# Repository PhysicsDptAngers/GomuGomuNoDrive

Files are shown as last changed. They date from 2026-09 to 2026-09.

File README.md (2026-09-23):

# Rubber Zener (GomuGomuNoDrive): Analog Circuit & Anti-Aliased Virtual Analog Model

This repository provides open-source hardware designs, physical bench measurement datasets, numerical simulation routines, and real-time DSP emulations for the **Rubber Zener** clipping topology.

The Rubber Zener is a parameterized audio clipping circuit based on the bipolar junction transistor (BJT) $V_{be}$ multiplier, augmented with local passive and reactive networks. It allows decoupled analog tuning of positive and negative conduction thresholds, soft-knee transition slopes, deep-saturation current ceilings, frequency-dependent clipping profiles, and envelope-dependent DC baseline sag.

> **Academic Context:**  
> This repository contains the reference implementation, experimental datasets, and validation routines accompanying the research paper:  
> *The Rubber Zener Clipping Topology: Circuit Analysis, Dynamic Characterization, and Anti-Aliased Virtual Analog Modeling* (currently under peer review).

---

## コムコム の Drive  (Gomu Gomu No Drive) ?

The $V_{be}$ multiplier circuit is sometimes called "Rubber Zener" because, like rubber, its threshold is malleable. In pop culture, the most well-known "rubber man" is *Luffy* (ルフィ) from *One Piece* (ワンピース). His iconic attack names start with "ゴムゴム" (Gomu Gomu) since ゴム (gomu) in Japanese means rubber. Hence the name of this distortion pedal: コムコム の Drive (Gomu Gomu No Drive).

---

## Repository Structure

```text
GomuGomuNoDrive/
├── Data/
│   ├── AC/                                # AC bench measurements, steady-state datasets, and fitting scripts
│   └── DC characteristics/                # Static I-V measurement datasets
├── Hardware/
│   ├── GomuGomuNoDrive_hard/              # Shunt dipole hard-clipping implementation (KiCad, 3D models, Gerbers)
│   └── GomuGomuNoDrive_Soft/              # Feedback loop soft-clipping implementation (KiCad, BOM, production files)
├── NumericalSimulation/                   # SPICE benchmarks, 4D ODE solvers, harmonic balance, and validation routines
└── Software/
    ├── Faust/                             # Faust core DSP architecture and C++ wrappers
    ├── JesuSonic/                         # Real-time JSFX implementation for Cockos REAPER
    └── Juce Plugin/                       # Full C++ audio plugin project (VST3, CLAP, LV2, Standalone)
```

#### Pre-compiled Binaries

Pre-compiled binaries for 64-bit Windows and Linux systems (VST3 and Standalone) are provided under the [Releases](../../releases) section.

---

## License

This project adopts a multi-licensing scheme adapted to its different components:

- **Software** (JUCE audio plugin, DSP solvers, simulation scripts): Licensed under the [GNU General Public License v3.0](LICENSE-GPL.txt) (GPL-3.0-or-later). Bundled cabinet impulse responses are licensed under GPL-2.0-or-later (Copyright © 2013 David Fau Casquel / Guitarix project).
- **Hardware** (KiCad schematics, PCB layouts, manufacturing files): Licensed under the [CERN Open Hardware Licence Version 2 – Strongly Reciprocal](LICENSE-CERN.txt) (CERN-OHL-S-2.0).
- **Documentation & Data** (Manuscript, figures, measurement datasets): Licensed under the [Creative Commons Attribution 4.0 International License](https://creativecommons.org/licenses/by/4.0/) (CC-BY-4.0).

---

## Citation

If you use this circuit topology, DSP implementation, or dataset in academic work or derivative projects, please cite:

TBA !

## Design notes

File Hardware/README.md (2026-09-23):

# Hardware

Contains complete CAD files, schematics, PCB layouts, and fabrication packages:

* **`GomuGomuNoDrive_hard`**: The primary shunt-to-ground clipping dipole topology characterized in the paper.
* **`GomuGomuNoDrive_Soft`**: Alternative operational amplifier feedback implementation (compatible with classic LM308 / dual op-amp footprints).

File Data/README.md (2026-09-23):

# Experimental Data 

Physical bench measurements acquired via digital storage oscilloscopes and automated SCPI test benches:

* **`Data/AC`**: Calibrated time-domain AC voltage captures across various frequency and reactive network configurations, along with global parameter extraction scripts.
* **`Data/DC characteristics`**: Quasi-static $I-V$ sweeps documenting threshold voltage shifts ($\alpha$), soft-knee curvature ($R_k$), and plateau resistance ($R_p$).

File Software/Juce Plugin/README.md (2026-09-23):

# GomuGomuNoDrive — JUCE Audio Plugin

This directory contains the reference C++ implementation of the **GomuGomuNoDrive** (Rubber Zener) virtual analog audio plugin built with the [JUCE framework](https://juce.com/) (version 8.0.13).

The plugin features:
- A real-time, four-dimensional implicit Newton-Raphson solver modeling the physical Ebers-Moll BJT transport equations and Shockley diode characteristics.
- 2x polyphase half-band IIR multirate oversampling (>90 dB stopband rejection).
- Dual 12-band graphic equalizers (pre-distortion drive sculpting and post-distortion tone shaping).
- Dynamic CRT-style visualizers (static I/V transfer characteristic and real-time dual-trace time-domain waveform monitor).
- Integrated zero-latency cabinet impulse response (IR) convolution engine.
- Targets: **VST3**, **CLAP**, **LV2**, and **Standalone**.

---

## Important Files

- `CMakeLists.txt` — CMake build configuration and target definitions.
- `PluginProcessor.h` / `PluginProcessor.cpp` — Core DSP pipeline: APVTS parameter layout, implicit 4D Newton-Raphson solver (`RubberZener`), oversampler, and convolution engine.
- `PluginEditor.h` / `PluginEditor.cpp` — Graphical user interface, custom hardware LookAndFeel (Davies 1510 knobs, vintage levers), graphic EQ components, and CRT scopes.
- `Resources/IR/` — Bundled speaker cabinet impulse response collections (`BestPlugins_Amps` and `BestPlugins_Bands`).

---

## Building from CLI

> **Note:** Pre-compiled binaries for Linux and Windows (VST3, CLAP, Standalone) are available under the GitHub [Releases](../../releases) section if you do not wish to build from source.

### Linux (Debian / Ubuntu)

1. **Install system dependencies:**

   ```bash
   sudo apt update
   sudo apt install -y build-essential cmake ninja-build git \
       libasound2-dev libjack-jackd2-dev libgl1-mesa-dev libglu1-mesa-dev \
       libx11-dev libxinerama-dev libxext-dev libfreetype6-dev
   ```

2. **Clone the JUCE framework (tested with version 8.0.13):**

#### Option A: Tested version (8.0.13)
git clone --depth 1 --branch 8.0.13 https://github.com/juce-framework/JUCE.git JUCE

#### Option B: Latest version (master branch)
git clone --depth 1 https://github.com/juce-framework/JUCE.git JUCE

3. **Configure and compile with CMake and Ninja:**

   ```bash
   cmake -B build -G Ninja -DCMAKE_BUILD_TYPE=Release
   cmake --build build --config Release -j$(nproc)
   ```

   Compiled artifacts (VST3, CLAP, LV2, and Standalone binary) will be generated inside `build/GomuGomuNoDrive_artefacts/Release/`.

---

### Windows (CLI)

1. **Prerequisites:**
   - Visual Studio Build Tools (or Visual Studio Community) with the **C++ Desktop Development** workload installed.
```powershell
winget install --id Microsoft.VisualStudio.2022.BuildTools --override "--passive --wait --add Microsoft.VisualStudio.Workload.VCTools --includeRecommended"
```

   - [CMake](https://cmake.org/download/) (>= 3.22) and [Git](https://git-scm.com/) added to your system `PATH`.
   - Optional: [Ninja](https://github.com/ninja-build/ninja/releases) for faster parallel builds.

```powershell
# Git and CMake
winget install --id Git.Git -e --source winget
winget install --id Kitware.CMake -e --source winget --override "ADD_CMAKE_TO_PATH=System"

# Ninja (optionnal)
winget install --id Ninja-build.Ninja -e --source winget
```

2. **Clone the JUCE framework (version 8.0.13):**

   Open PowerShell or the Developer Command Prompt:

   ```powershell
   git clone --depth 1 --branch 8.0.13 https://github.com/juce-framework/JUCE.git JUCE
   ```

3. **Configure and compile:**

   *Using Ninja (from Developer Command Prompt):*
   ```powershell
   cmake -B build -G Ninja -DCMAKE_BUILD_TYPE=Release
   cmake --build build --config Release
   ```

   *Or using the default MSVC generator:*
   ```powershell
   cmake -B build -G "Visual Studio 17 2022" -A x64
   cmake --build build --config Release --parallel
   ```

   Binaries will be available in `build/GomuGomuNoDrive_artefacts/Release/`.

---

## Impulse Responses (IR) & Licensing

- **Plugin Source Code:** Released under the [GNU General Public License v3.0](https://www.gnu.org/licenses/gpl-3.0.html) (GPL-3.0-or-later).
- **Cabinet Impulse Responses (`Resources/IR/`):** Sourced from the open-source **Guitarix** project, collected and created by David Fau Casquel (BestPlugins). These IR files are licensed under the [GNU General Public License v2.0](https://www.gnu.org/licenses/old-licenses/gpl-2.0.html) (GPL-2.0-or-later). See `Resources/IR/BestPlugins_Amps/LICENSE` and `Resources/IR/BestPlugins_Bands/LICENSE` for full notices.

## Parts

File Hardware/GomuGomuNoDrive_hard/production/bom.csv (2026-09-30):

Designator | Footprint | Quantity | Value | LCSC Part #
C1 | 0805 | 1 | 22n - film
C10, C14, C15 | 0805 | 3 | 100n
C11, C17, C5, C7 | 0805 | 4 | 22n
C12, C13, C16 | 0805 | 3 | 1u
C18 | 0805 | 1 | 10u
C2, C3 | 0805 | 2 | 4n7
C6 | 0805 | 1 | 220n
C8, C9 | 0805 | 2 | 10n
D1, D2, D3 | D_SOD-123 | 3 | C8598
D4 | LED_D5.0mm_Clear | 1 | LED
J1 | BarrelJack_Horizontal | 1 | 9V
J2, J3 | Jack_6.35mm_Neutrik_NMJ6HCD2_Horizontal | 2 | AudioJack3
J5 | JST_EH_B6B-EH-A_1x06_P2.50mm_Vertical | 1 | Conn_01x06_Socket
Q1, Q2 | SOT-23 | 2 | BC850
R10 | 0805 | 1 | 1M
R11, R13, R16 | 0805 | 3 | 4k7
R12, R14, R15 | 0805 | 3 | 100
R17 | 0805 | 1 | 10k
R9 | 0805 | 1 | 6K8
RV11 | Potentiometer_Alpha_RD901F-40-00D_Single_Vertical | 1 | 100K_Log
RV12, RV5, RV6, RV8 | Potentiometer_Alpha_RD901F-40-00D_Single_Vertical | 4 | 5K
RV21 | Potentiometer_Alpha_RD901F-40-00D_Single_Vertical | 1 | 100K Log
RV3, RV4 | Potentiometer_Alpha_RD901F-40-00D_Single_Vertical | 2 | 50K
SW10, SW7, SW8 | SS12D00 | 3 | SW_DPDT_x2
SW11 | SS12D00 | 1 | SW_SPDT
SW3, SW4 | SW_MINI-SPDT-SW | 2 | SW_DPDT_x2
SW5, SW6 | SW_MINI-SPDT-SW | 2 | SW_SPDT_MSM
TP20 | PinHeader_1x01_P2.54mm_Vertical | 1 | -9V
TP21 | PinHeader_1x01_P2.54mm_Vertical | 1 | In
TP22 | PinHeader_1x01_P2.54mm_Vertical | 1 | In_DC
TP23 | PinHeader_1x01_P2.54mm_Vertical | 1 | pre_diode
TP24 | PinHeader_1x01_P2.54mm_Vertical | 1 | post_diode
TP25 | PinHeader_1x01_P2.54mm_Vertical | 1 | GND
TP26 | PinHeader_1x01_P2.54mm_Vertical | 1 | out
TP27 | PinHeader_1x01_P2.54mm_Vertical | 1 | 9V
U2 | SOIC-8_3.9x4.9mm_P1.27mm | 1 | TC7662Bx0A
U5 | SOIC-14_3.9x8.7mm_P1.27mm | 1 | OPA1679

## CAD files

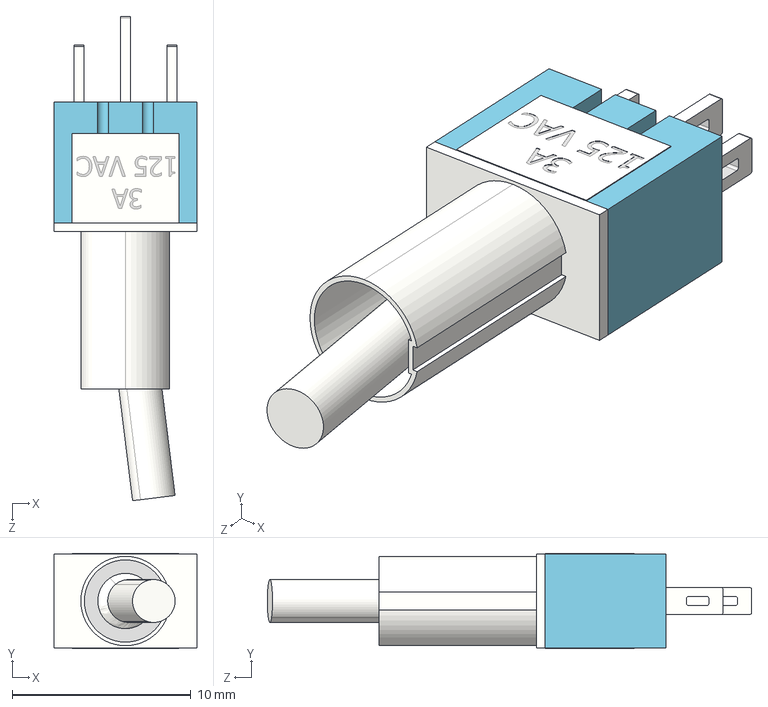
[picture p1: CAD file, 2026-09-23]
Hardware/GomuGomuNoDrive_hard/User Library-Toggle Switch Full.STEP
8.00 x 5.34 x 27.1 mm
Toggle Switch 3a 125V AC Lever
Toggle Switch 3a 125V AC

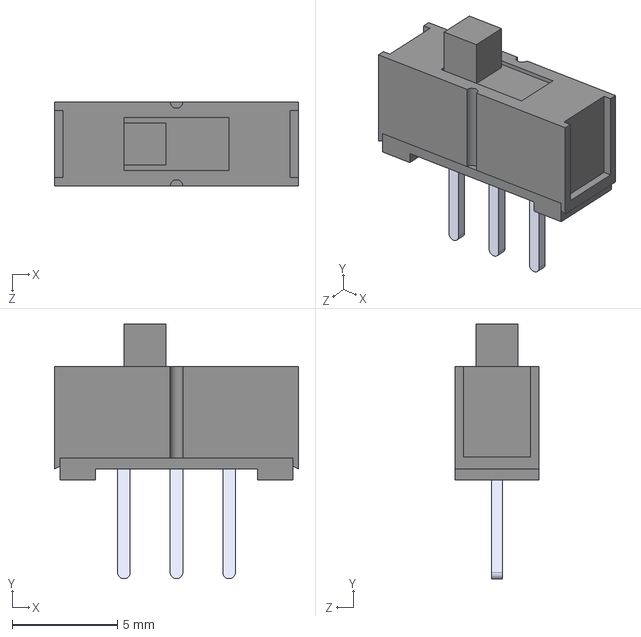
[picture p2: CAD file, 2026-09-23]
Hardware/GomuGomuNoDrive_hard/MINI-SPDT-SW.step
11.6 x 12.1 x 4.00 mm

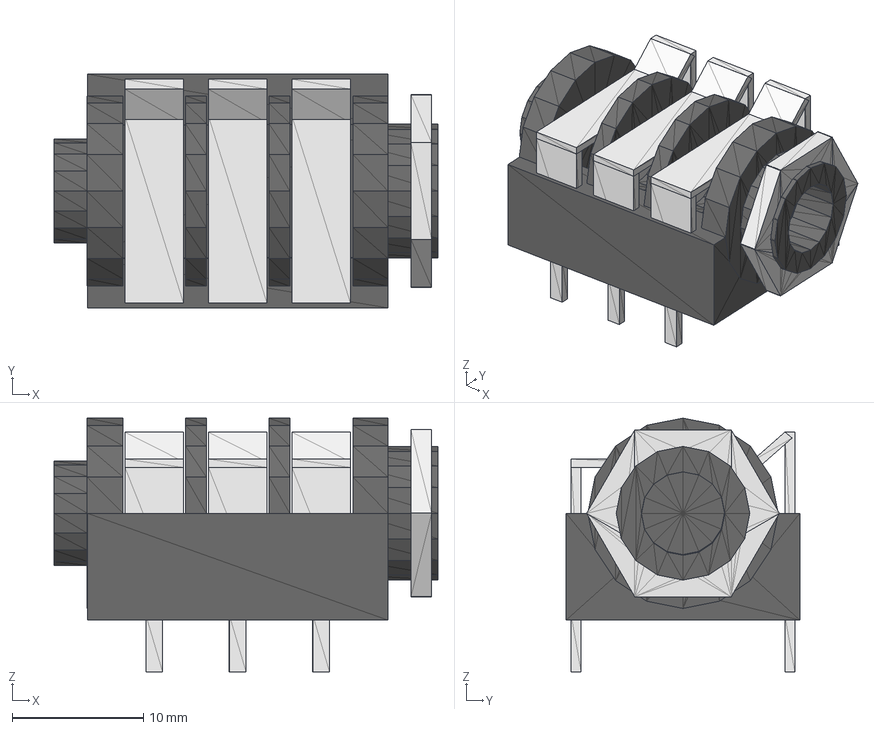
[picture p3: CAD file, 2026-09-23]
Hardware/GomuGomuNoDrive_Soft/NEUTRIKJKST.stp
29.2 x 17.8 x 19.3 mm
NEUTRIKJKST_2
NEUTRIKJKST_3
NEUTRIKJKST_4
NEUTRIKJKST_5
NEUTRIKJKST_6
NEUTRIKJKST_7
NEUTRIKJKST_8
NEUTRIKJKST_9
NEUTRIKJKST_10
NEUTRIKJKST_11
NEUTRIKJKST_12
NEUTRIKJKST_13
NEUTRIKJKST_14
NEUTRIKJKST_15
NEUTRIKJKST_16
NEUTRIKJKST_17
NEUTRIKJKST_18
NEUTRIKJKST_19
NEUTRIKJKST_20
NEUTRIKJKST_21
NEUTRIKJKST_22
NEUTRIKJKST_23
NEUTRIKJKST_24
NEUTRIKJKST_25
NEUTRIKJKST_26
NEUTRIKJKST_27
NEUTRIKJKST_28
NEUTRIKJKST_29
NEUTRIKJKST_30
NEUTRIKJKST_31
NEUTRIKJKST_32

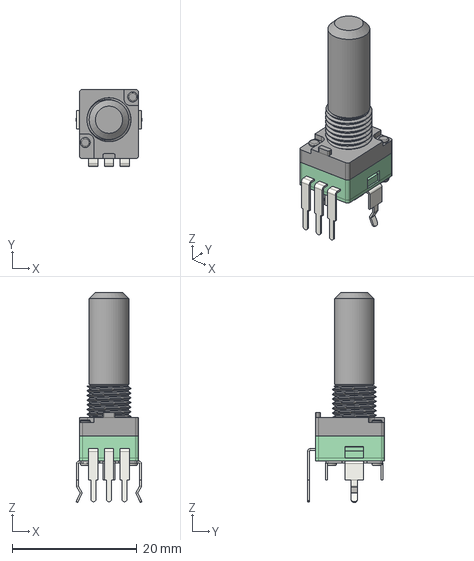
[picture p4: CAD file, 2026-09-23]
Hardware/GomuGomuNoDrive_Soft/ALPHA-RD901F-40.step
10.6 x 12.3 x 33.6 mm

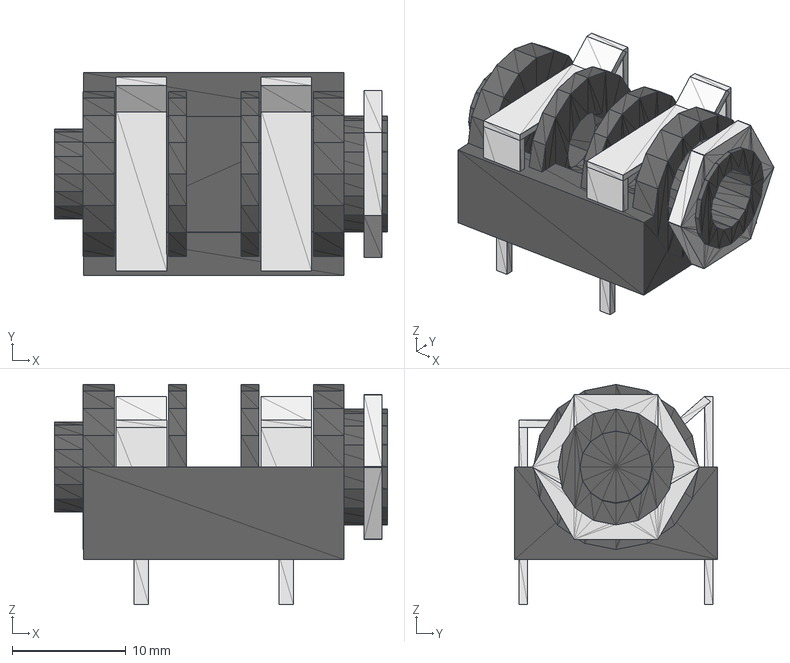
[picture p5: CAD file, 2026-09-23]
Hardware/GomuGomuNoDrive_Soft/NEUTRIKJK.stp
29.2 x 17.8 x 19.3 mm
NEUTRIKJK_2
NEUTRIKJK_3
NEUTRIKJK_4
NEUTRIKJK_5
NEUTRIKJK_6
NEUTRIKJK_7
NEUTRIKJK_8
NEUTRIKJK_9
NEUTRIKJK_10
NEUTRIKJK_11
NEUTRIKJK_12
NEUTRIKJK_13
NEUTRIKJK_14
NEUTRIKJK_15
NEUTRIKJK_16
NEUTRIKJK_17
NEUTRIKJK_18
NEUTRIKJK_19
NEUTRIKJK_20
NEUTRIKJK_21
NEUTRIKJK_22
NEUTRIKJK_23
NEUTRIKJK_24
NEUTRIKJK_25
NEUTRIKJK_26

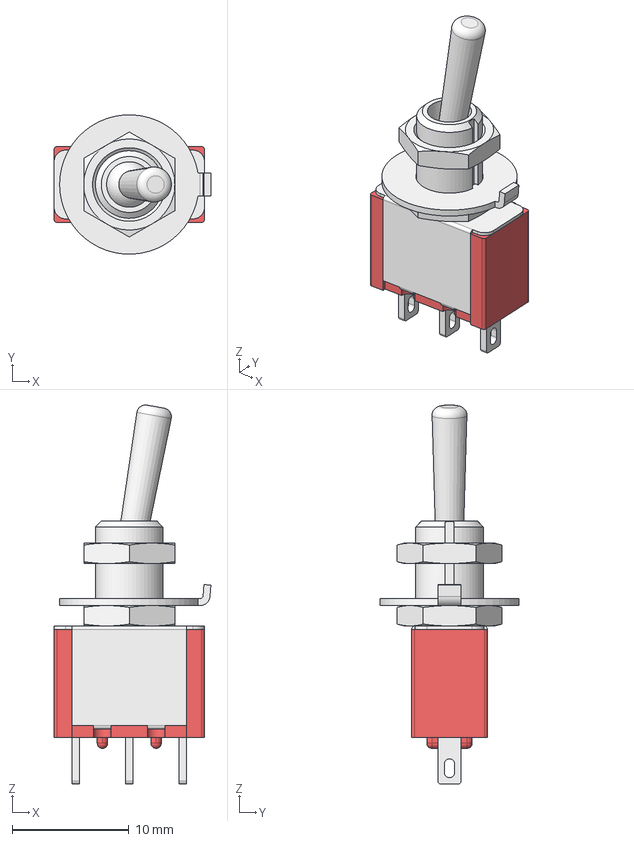
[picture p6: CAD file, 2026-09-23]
Hardware/GomuGomuNoDrive_hard/6mm SPDT Mini Toggle Switch.step
13.4 x 11.9 x 32.5 mm

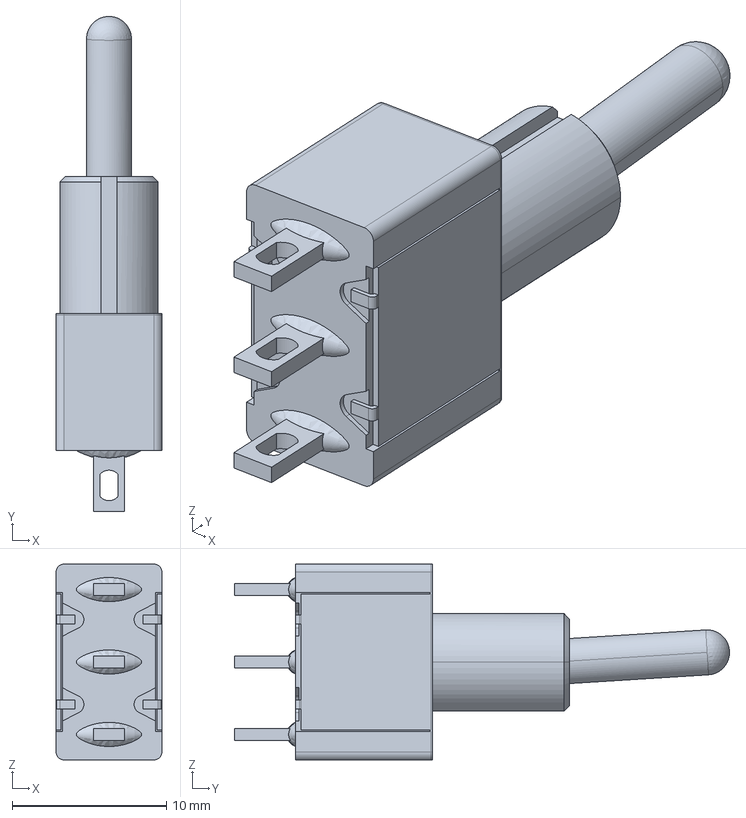
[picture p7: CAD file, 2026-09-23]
Hardware/GomuGomuNoDrive_hard/toggle_switch_1ms1t1b1m1qes.stp
6.86 x 32.1 x 12.7 mm

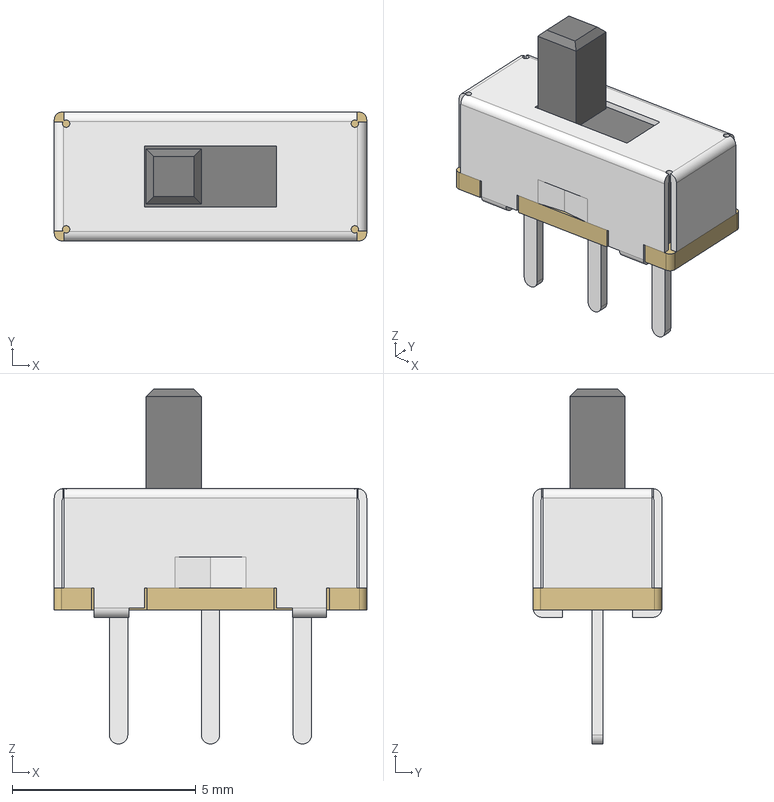
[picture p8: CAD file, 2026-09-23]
Hardware/GomuGomuNoDrive_hard/SPDT slide switch SS12D00.step
8.50 x 3.50 x 9.66 mm

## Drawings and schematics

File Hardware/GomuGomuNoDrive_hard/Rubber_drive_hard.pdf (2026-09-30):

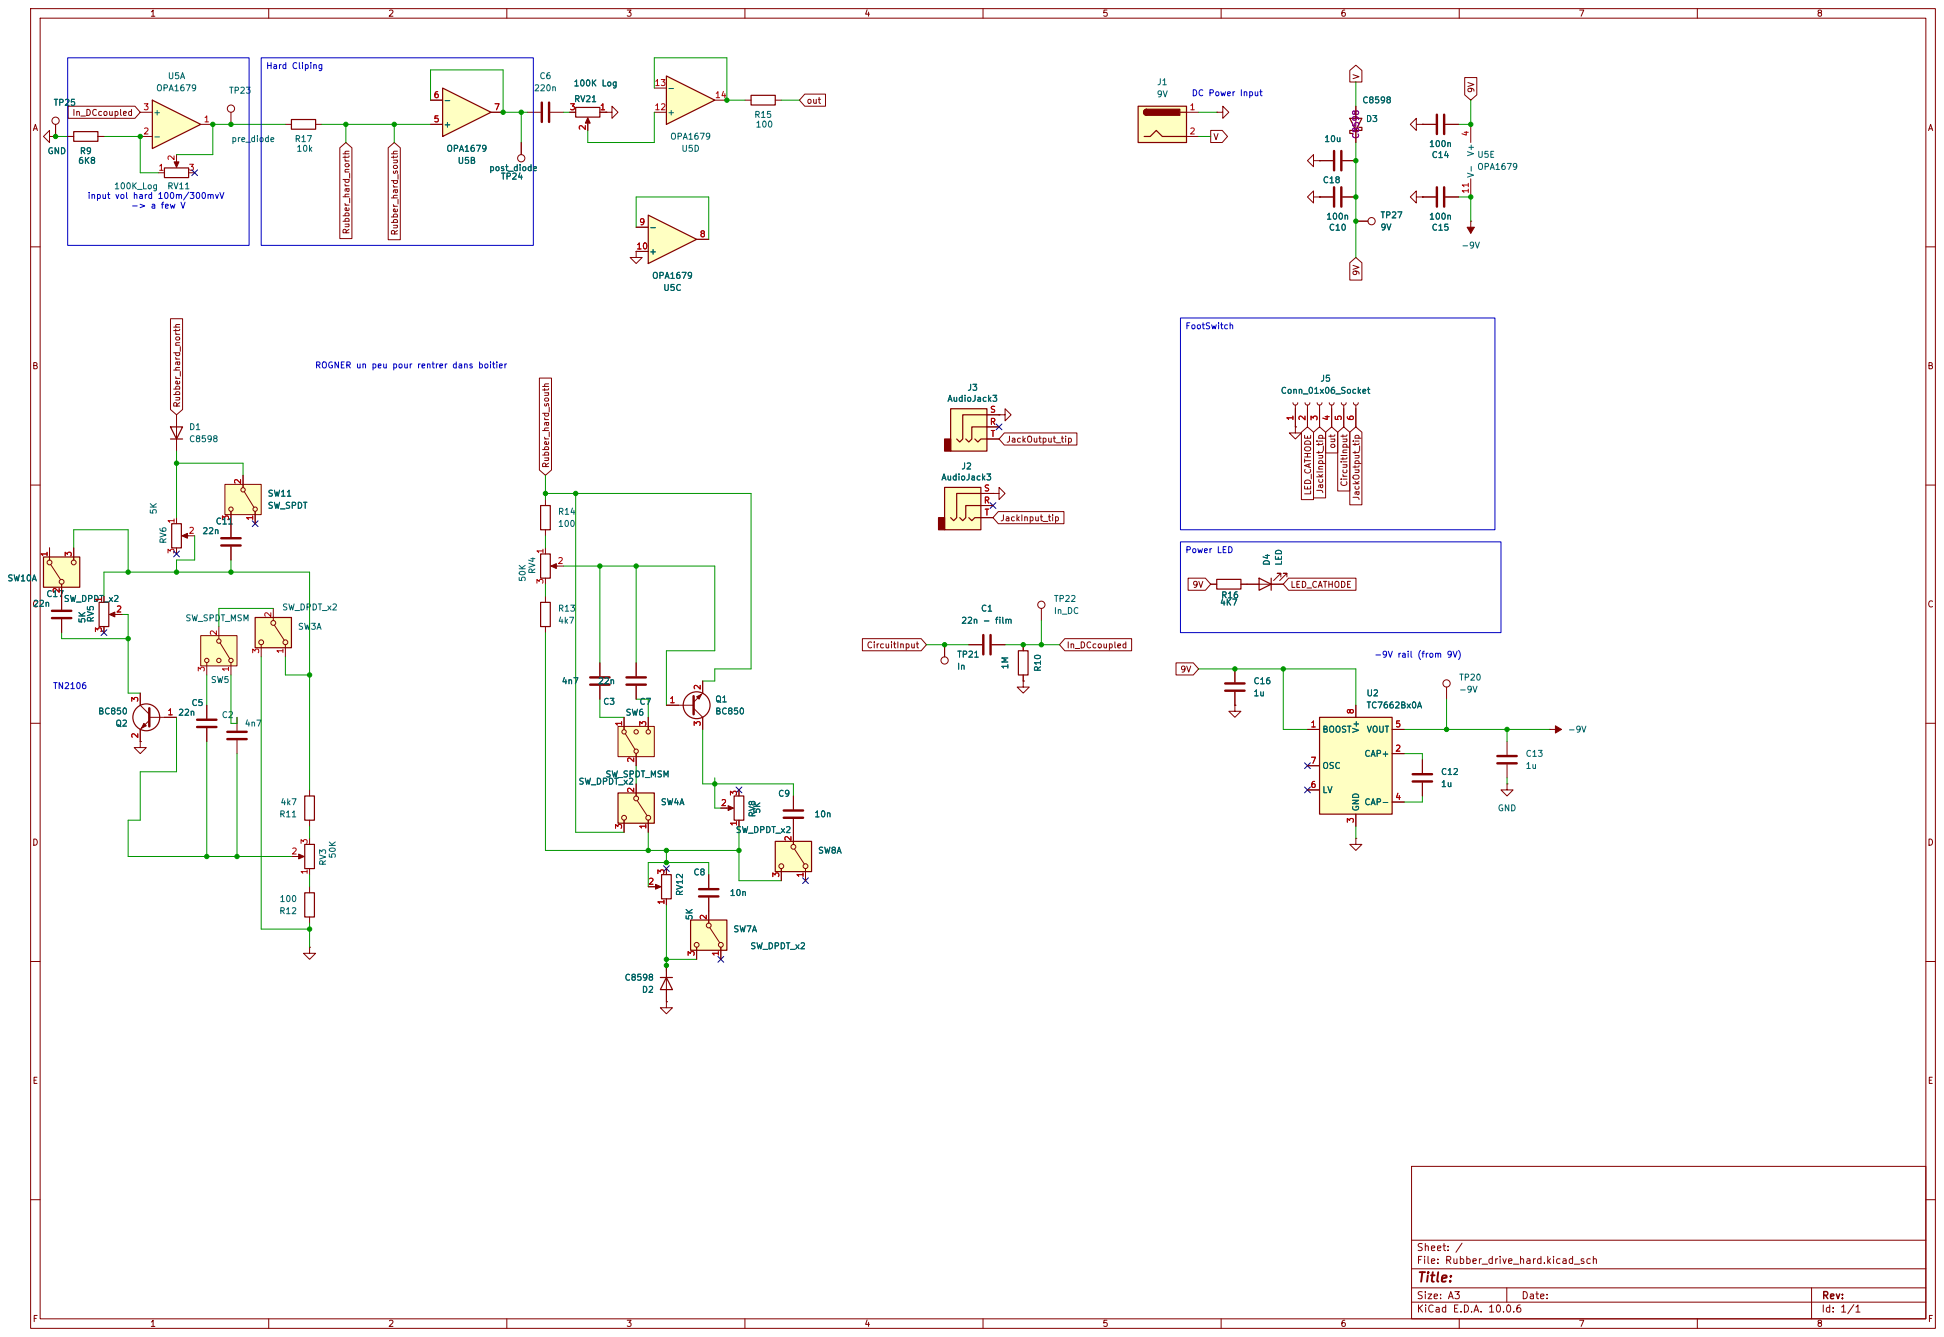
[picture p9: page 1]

Size: A3 | Rev: | F Date:
KiCad E.D.A. 10.0.6 | Id: 1/1

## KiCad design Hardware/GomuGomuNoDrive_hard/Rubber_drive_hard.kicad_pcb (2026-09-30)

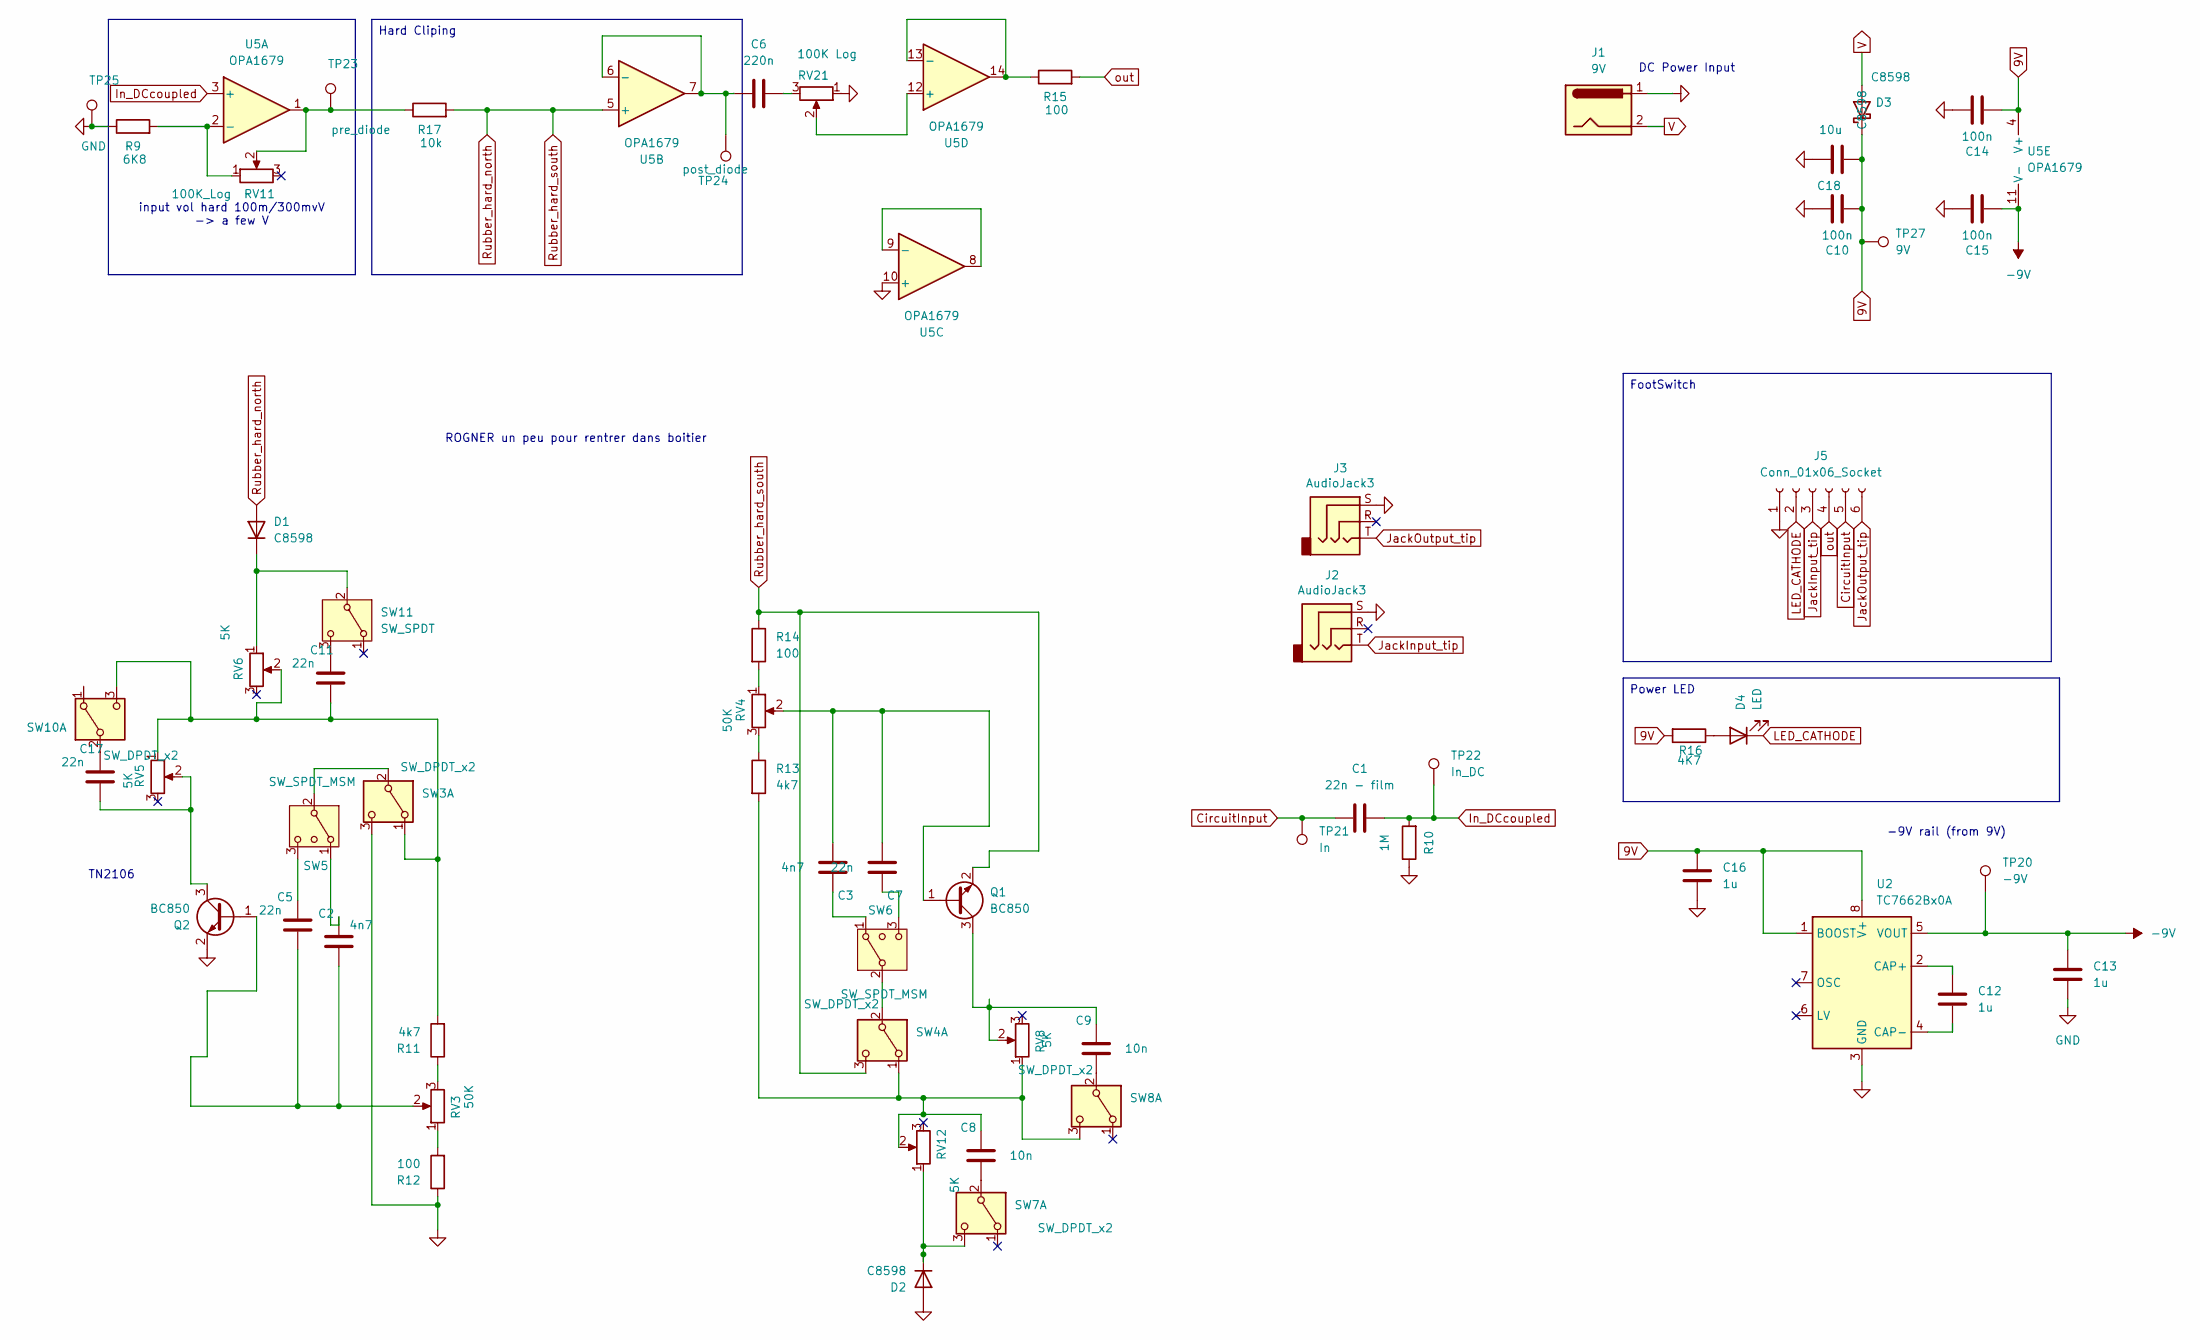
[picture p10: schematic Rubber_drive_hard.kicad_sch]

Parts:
C1: 22n - film; C_0805_2012Metric_Pad1.18x1.45mm_HandSolder
C2, C3: 4n7; C_0805_2012Metric_Pad1.18x1.45mm_HandSolder
C5, C7, C11, C17: 22n; C_0805_2012Metric_Pad1.18x1.45mm_HandSolder
C6: 220n; C_0805_2012Metric_Pad1.18x1.45mm_HandSolder
C8, C9: 10n; C_0805_2012Metric_Pad1.18x1.45mm_HandSolder
C10, C14, C15: 100n; C_0805_2012Metric_Pad1.18x1.45mm_HandSolder
C12, C13, C16: 1u; C_0805_2012Metric_Pad1.18x1.45mm_HandSolder
C18: 10u; C_0805_2012Metric_Pad1.18x1.45mm_HandSolder
D1, D2, D3: C8598; D_SOD-123
D4: LED; LED_D5.0mm_Clear
J1: 9V; BarrelJack_Horizontal
J2, J3: AudioJack3; Jack_6.35mm_Neutrik_NMJ6HCD2_Horizontal
J5: Conn_01x06_Socket; JST_EH_B6B-EH-A_1x06_P2.50mm_Vertical
Q1, Q2: BC850; SOT-23
R9: 6K8; R_0805_2012Metric_Pad1.20x1.40mm_HandSolder
R10: 1M; R_0805_2012Metric_Pad1.20x1.40mm_HandSolder
R11, R13: 4k7; R_0805_2012Metric_Pad1.20x1.40mm_HandSolder
R12, R14, R15: 100; R_0805_2012Metric_Pad1.20x1.40mm_HandSolder
R16: 4K7; R_0805_2012Metric_Pad1.20x1.40mm_HandSolder
R17: 10k; R_0805_2012Metric_Pad1.20x1.40mm_HandSolder
RV3, RV4: 50K; Potentiometer_Alpha_RD901F-40-00D_Single_Vertical
RV5, RV6, RV8, RV12: 5K; Potentiometer_Alpha_RD901F-40-00D_Single_Vertical
RV11: 100K_Log; Potentiometer_Alpha_RD901F-40-00D_Single_Vertical
RV21: 100K Log; Potentiometer_Alpha_RD901F-40-00D_Single_Vertical
SW3, SW4: SW_DPDT_x2; SW_MINI-SPDT-SW
SW5, SW6: SW_SPDT_MSM; SW_MINI-SPDT-SW
SW7, SW8, SW10: SW_DPDT_x2; SS12D00
SW11: SW_SPDT; SS12D00
TP20: -9V; PinHeader_1x01_P2.54mm_Vertical
TP21: In; PinHeader_1x01_P2.54mm_Vertical
TP22: In_DC; PinHeader_1x01_P2.54mm_Vertical
TP23: pre_diode; PinHeader_1x01_P2.54mm_Vertical
TP24: post_diode; PinHeader_1x01_P2.54mm_Vertical
TP25: GND; PinHeader_1x01_P2.54mm_Vertical
TP27: 9V; PinHeader_1x01_P2.54mm_Vertical
U2: TC7662Bx0A; SOIC-8_3.9x4.9mm_P1.27mm
U5: OPA1679; SOIC-14_3.9x8.7mm_P1.27mm

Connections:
9V: C10.2, C14.2, C16.2, C18.2, D3.1 (K), R16.2, TP27.1 (1_1), U2.1 (BOOST), U2.8 (V+), U5.4 (V+)
-9V: C13.2, C15.2, TP20.1 (1_1), U2.5 (VOUT), U5.11 (V-)
CircuitInput: C1.1, J5.5, TP21.1 (1_1)
GND: C10.1, C13.1, C14.1, C15.1, C16.1, C18.1, D2.2 (A), J1.1, J2.S, J3.S, J5.1, Q2.2 (E), R9.1, R10.1, R12.1, RV21.1, SW3.3 (C), TP25.1 (1_1), U2.3 (GND), U5.10 (+)
In_DCcoupled: C1.2, R10.2, TP22.1 (1_1), U5.3 (+)
JackInput_tip: J2.T, J5.3
JackOutput_tip: J3.T, J5.6
LED_CATHODE: D4.1 (K), J5.2
unnamed: C2.1, SW5.1
unnamed: C3.1, SW6.1
unnamed: C6.2, RV21.3
unnamed: D1.1 (K), RV6.1, SW11.2 (B)
unnamed: D2.1 (K), RV12.1, SW7.3 (C)
unnamed: D4.2 (A), R16.1
unnamed: C3.2, C7.2, Q1.1 (B), RV4.2
unnamed: C9.1, Q1.3 (C), RV8.2
unnamed: C2.2, C5.2, Q2.1 (B), RV3.2
unnamed: C17.2, Q2.3 (C), RV5.2
unnamed: R11.1, RV3.3
unnamed: R12.2, RV3.1
unnamed: R13.1, RV4.3
unnamed: R14.2, RV4.1
unnamed: R17.1, RV11.2, TP23.1 (1_1), U5.1
unnamed: SW3.2 (B), SW5.2 (3)
unnamed: C8.1, R13.2, RV8.1, RV12.2, SW4.1 (A), SW8.3 (C)
unnamed: SW4.2 (B), SW6.2 (3)
unnamed: C5.1, SW5.3 (4)
unnamed: C7.1, SW6.3 (4)
unnamed: C8.2, SW7.2 (B)
unnamed: C9.2, SW8.2 (B)
unnamed: C17.1, SW10.2 (B)
unnamed: C11.2, R11.2, RV5.1, RV6.2, SW3.1 (A), SW10.3 (C)
unnamed: C11.1, SW11.3 (C)
unnamed: C12.2, U2.2 (CAP+)
unnamed: C12.1, U2.4 (CAP-)
unnamed: R9.2, RV11.1, U5.2 (-)
unnamed: C6.1, TP24.1 (1_1), U5.6 (-), U5.7
unnamed: U5.8, U5.9 (-)
unnamed: RV21.2, U5.12 (+)
unnamed: R15.1, U5.13 (-), U5.14
Rubber_hard_north: D1.2 (A), Q1.2 (E), R14.1, R17.2, SW4.3 (C), U5.5 (+)
V: D3.2 (A), J1.2
out: J5.4, R15.2; also elsewhere on the board

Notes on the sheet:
input vol hard 100m/300mvV -> a few V
TN2106
-9V rail (from 9V)
ROGNER un peu pour rentrer dans boitier
DC Power Input
FootSwitch
Hard Cliping
Power LED

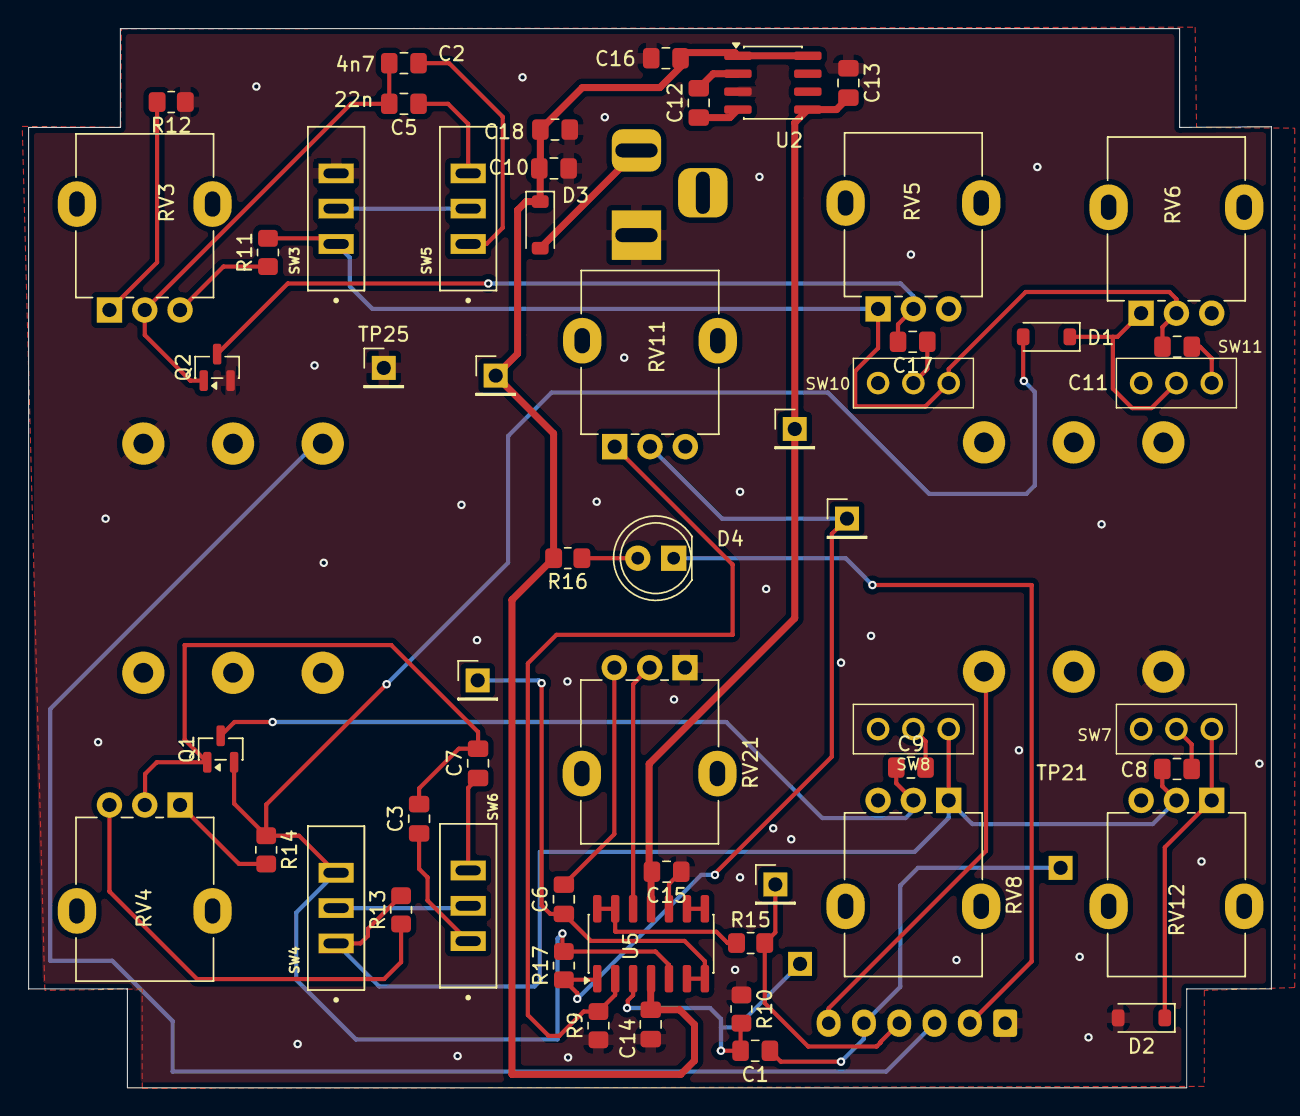
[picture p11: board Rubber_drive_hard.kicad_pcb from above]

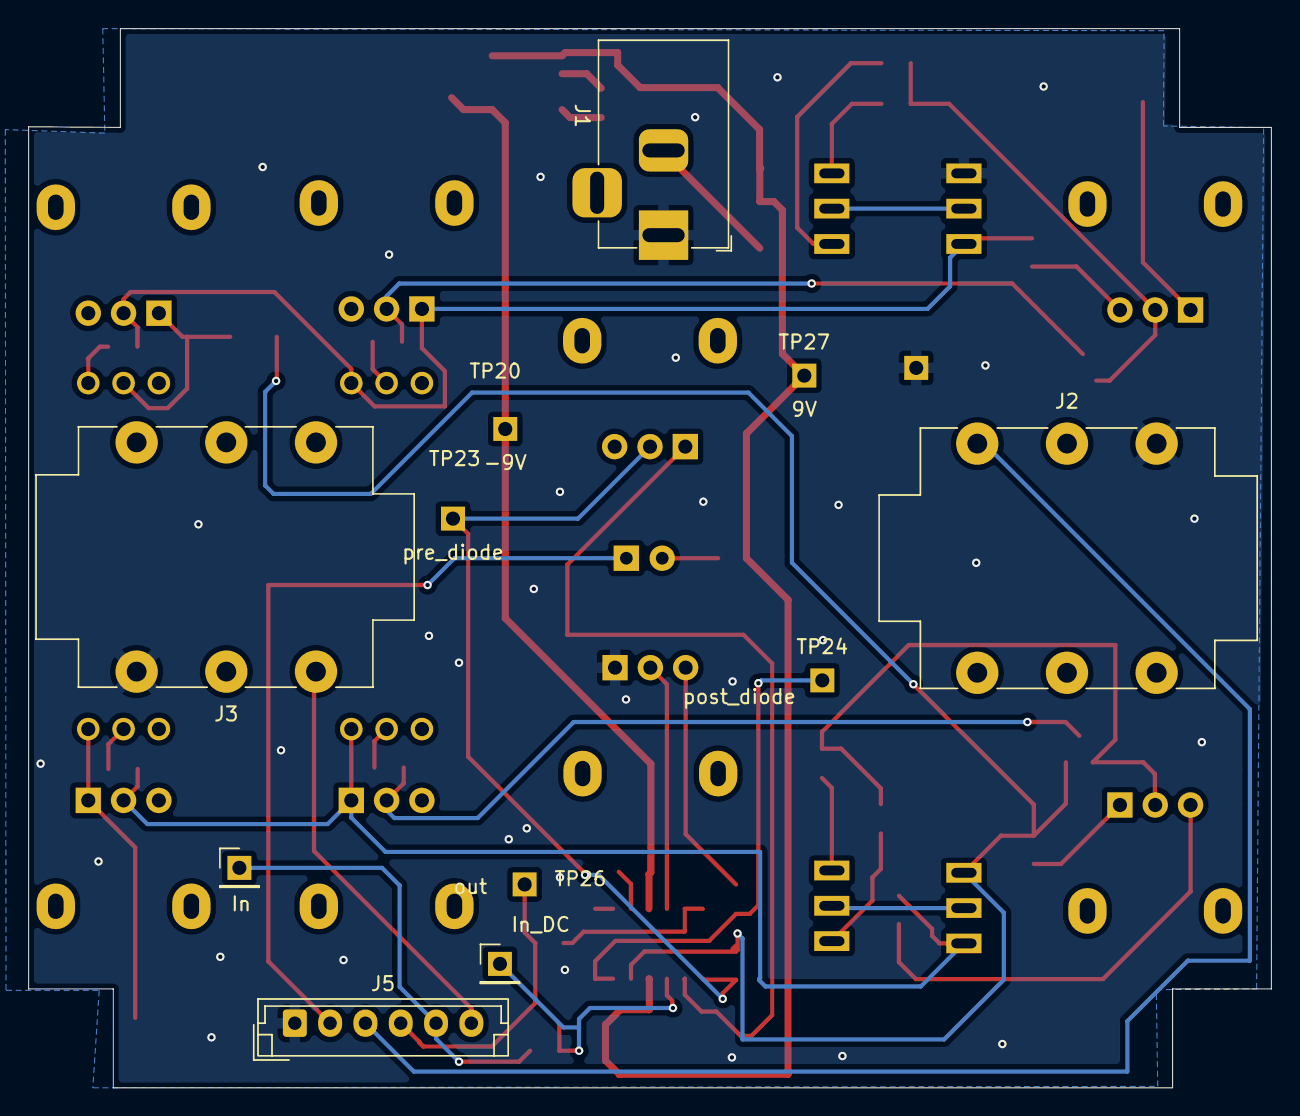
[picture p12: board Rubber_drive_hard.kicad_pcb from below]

Board: 2 copper layers, 88.0 x 75.0 mm, 62 parts (6 on the bottom side), 43 nets.

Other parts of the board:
TP26: out; PinHeader_1x01_P2.54mm_Vertical

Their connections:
out: TP26.1 (1_1); also elsewhere on the board

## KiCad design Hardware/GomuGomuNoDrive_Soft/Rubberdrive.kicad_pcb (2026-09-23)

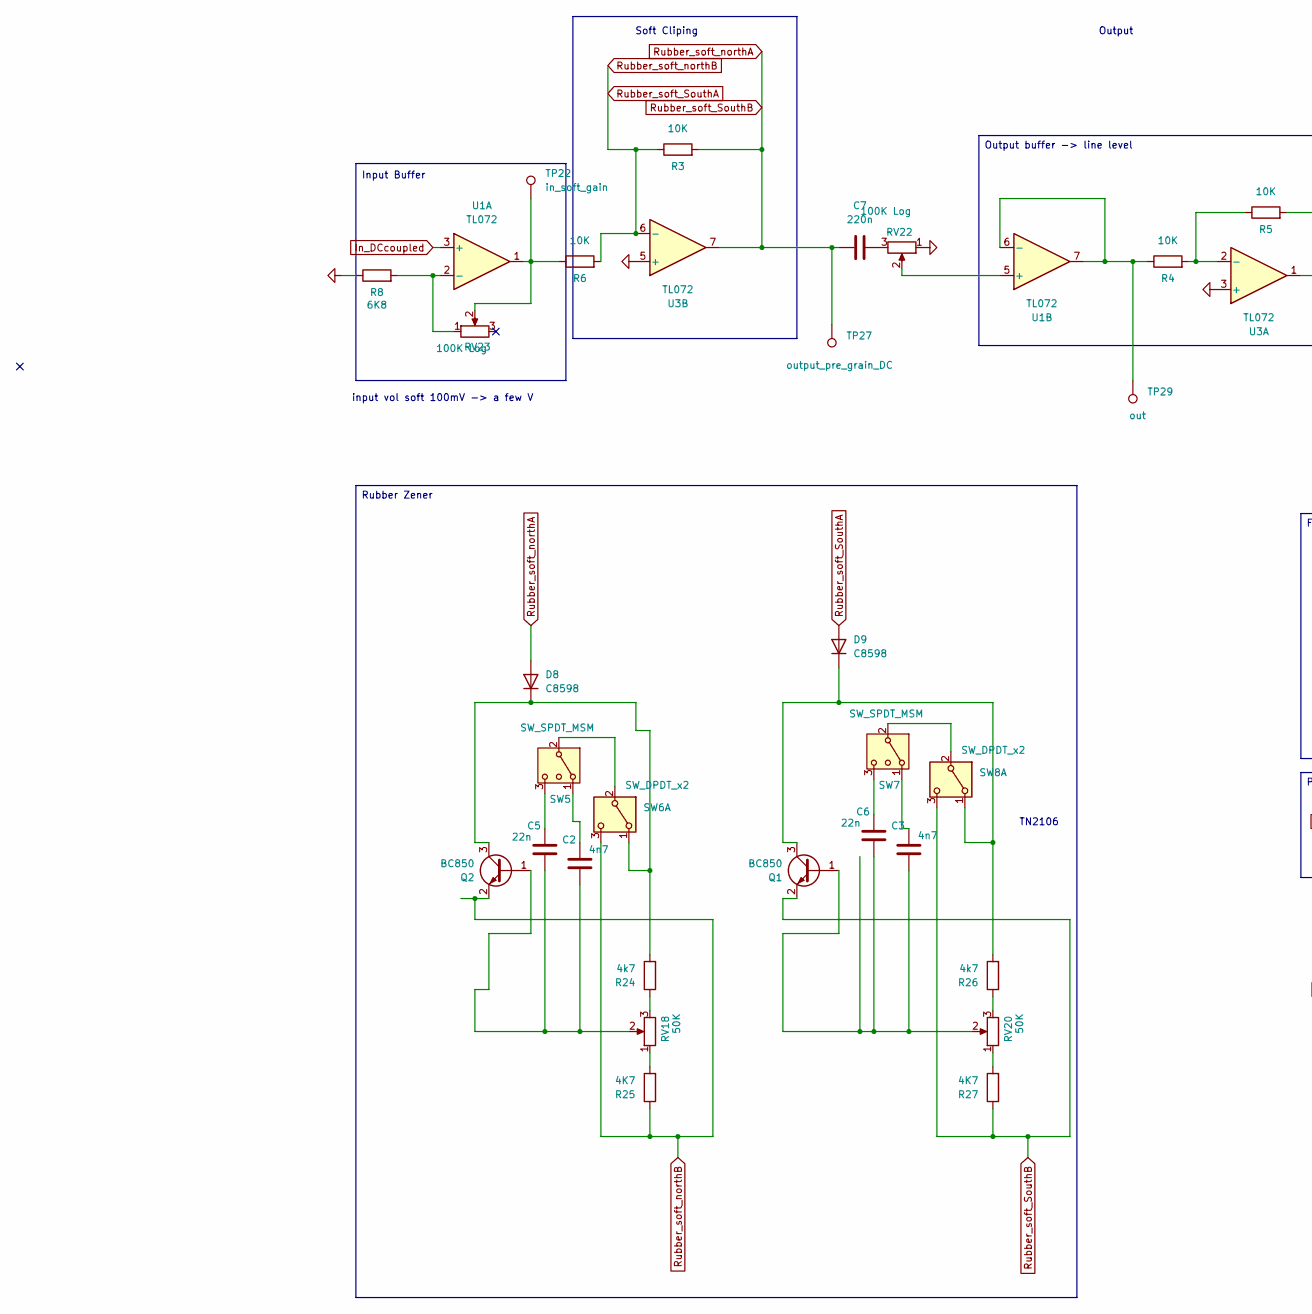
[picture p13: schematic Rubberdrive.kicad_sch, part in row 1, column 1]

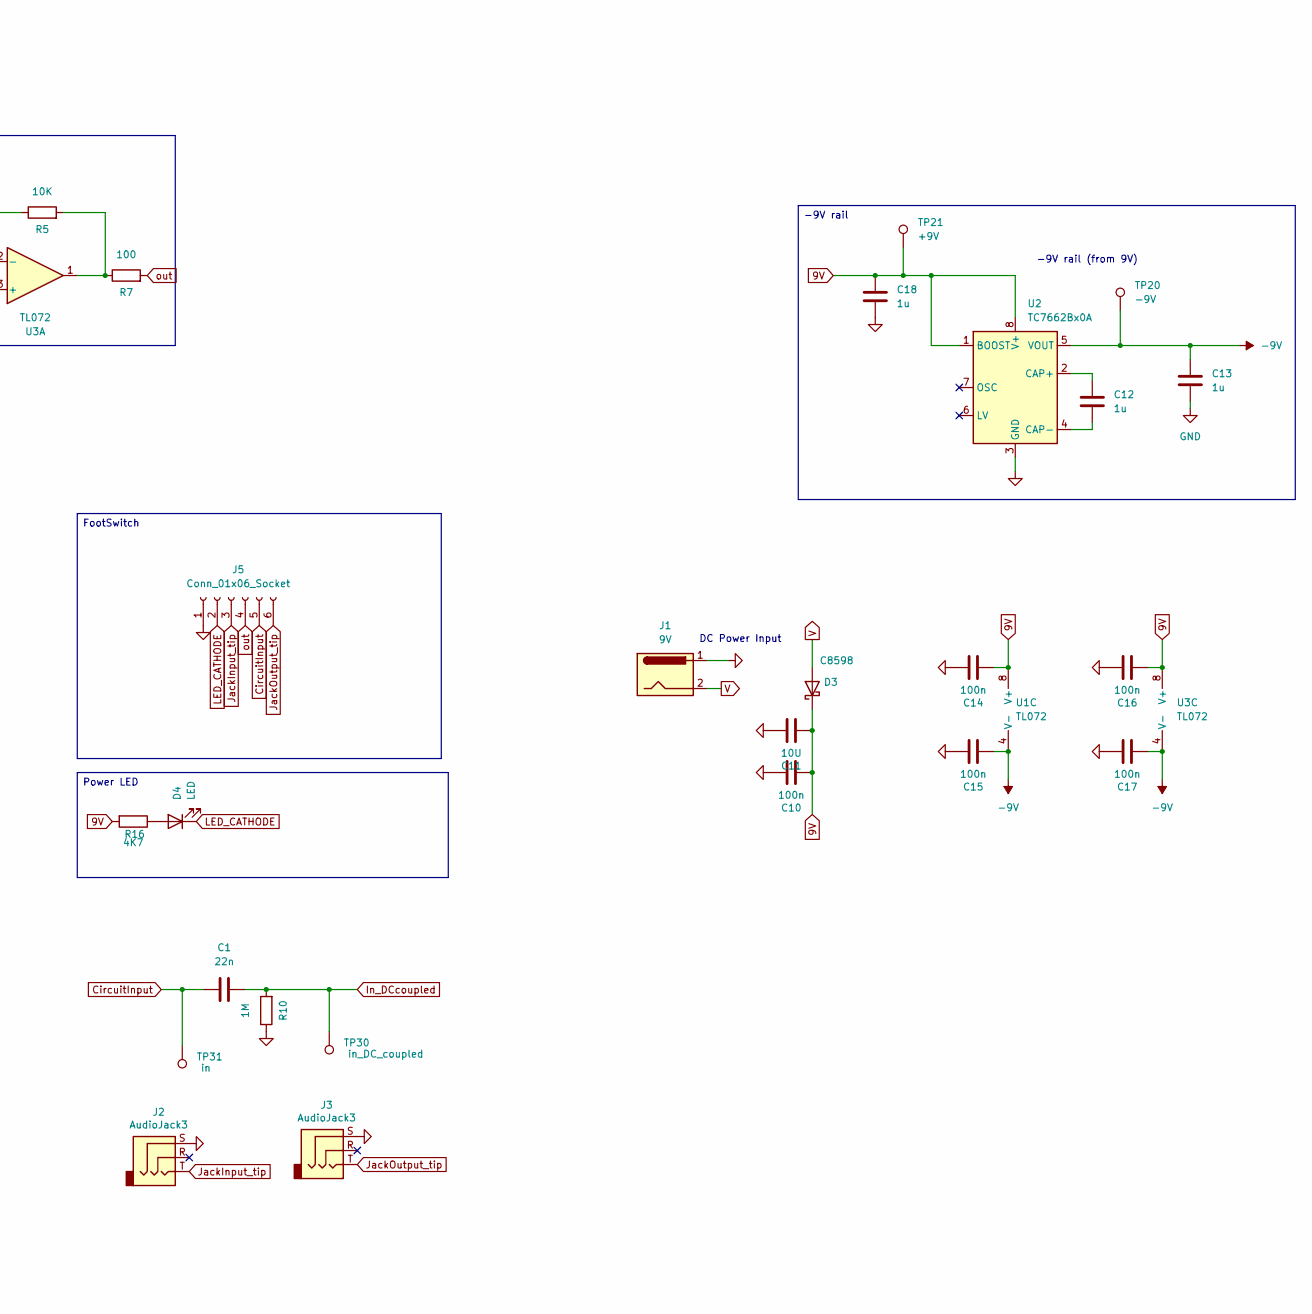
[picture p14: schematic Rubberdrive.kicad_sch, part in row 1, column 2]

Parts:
C1, C5, C6: 22n; C_0805_2012Metric_Pad1.18x1.45mm_HandSolder
C2, C3: 4n7; C_0805_2012Metric_Pad1.18x1.45mm_HandSolder
C7: 220n; C_0805_2012Metric_Pad1.18x1.45mm_HandSolder
C10, C14, C15, C16, C17: 100n; C_0805_2012Metric_Pad1.18x1.45mm_HandSolder
C11: 10U; C_1206_3216Metric_Pad1.33x1.80mm_HandSolder
C12, C13, C18: 1u; C_0805_2012Metric_Pad1.18x1.45mm_HandSolder
D3, D8, D9: C8598; D_SOD-123
D4: LED; LED_D5.0mm_Clear
J1: 9V; BarrelJack_Horizontal
J2, J3: AudioJack3; Jack_6.35mm_Neutrik_NMJ6HCD2_Horizontal
J5: Conn_01x06_Socket; JST_EH_B6B-EH-A_1x06_P2.50mm_Vertical
Q1, Q2: BC850; SOT-23
R3, R4, R5, R6: 10K; R_0805_2012Metric_Pad1.20x1.40mm_HandSolder
R7: 100; R_0805_2012Metric_Pad1.20x1.40mm_HandSolder
R8: 6K8; R_0805_2012Metric_Pad1.20x1.40mm_HandSolder
R10: 1M; R_0805_2012Metric_Pad1.20x1.40mm_HandSolder
R16, R25, R27: 4K7; R_0805_2012Metric_Pad1.20x1.40mm_HandSolder
R24, R26: 4k7; R_0805_2012Metric_Pad1.20x1.40mm_HandSolder
RV18, RV20: 50K; Potentiometer_Alpha_RD901F-40-00D_Single_Vertical
RV22, RV23: 100K Log; Potentiometer_Alpha_RD901F-40-00D_Single_Vertical
SW5, SW7: SW_SPDT_MSM; SW_MINI-SPDT-SW
SW6, SW8: SW_DPDT_x2; SW_MINI-SPDT-SW
TP20: -9V; PinHeader_1x01_P2.54mm_Vertical
TP21: +9V; PinHeader_1x01_P2.54mm_Vertical
TP22: in_soft_gain; PinHeader_1x01_P2.54mm_Vertical
TP27: output_pre_grain_DC; PinHeader_1x01_P2.54mm_Vertical
TP29: out; PinHeader_1x01_P2.54mm_Vertical
TP30: in_DC_coupled; PinHeader_1x01_P2.54mm_Vertical
TP31: in; PinHeader_1x01_P2.54mm_Vertical
U1, U3: TL072; DIP-8_W7.62mm
U2: TC7662Bx0A; SOIC-8_3.9x4.9mm_P1.27mm

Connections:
9V: C10.2, C11.2, C14.2, C16.2, C18.2, D3.1 (K), R16.2, TP21.1 (1_1), U1.8 (V+), U2.1 (BOOST), U2.8 (V+), U3.8 (V+)
-9V: C13.2, C15.2, C17.2, TP20.1 (1_1), U1.4 (V-), U2.5 (VOUT), U3.4 (V-)
CircuitInput: C1.1, J5.5, TP31.1 (1_1)
GND: C10.1, C11.1, C13.1, C14.1, C15.1, C16.1, C17.1, C18.1, J1.1, J2.S, J3.S, J5.1, R8.1, R10.1, RV22.1, U2.3 (GND), U3.3 (+), U3.5 (+)
In_DCcoupled: C1.2, R10.2, TP30.1 (1_1), U1.3 (+)
JackInput_tip: J2.T, J5.3
JackOutput_tip: J3.T, J5.6
LED_CATHODE: D4.1 (K), J5.2
unnamed: C2.1, SW5.1
unnamed: C3.1, SW7.1
unnamed: C7.2, RV22.3
unnamed: D4.2 (A), R16.1
unnamed: D8.1 (K), Q2.3 (C), R24.2, SW6.1 (A)
unnamed: D9.1 (K), Q1.3 (C), R26.2, SW8.1 (A)
unnamed: C3.2, C6.2, Q1.1 (B), RV20.2
unnamed: C2.2, C5.2, Q2.1 (B), RV18.2
unnamed: R5.2, R7.1, U3.1
unnamed: R6.1, RV23.2, TP22.1 (1_1), U1.1
unnamed: R24.1, RV18.3
unnamed: R25.2, RV18.1
unnamed: R26.1, RV20.3
unnamed: R27.2, RV20.1
unnamed: SW5.2 (3), SW6.2 (B)
unnamed: C5.1, SW5.3 (4)
unnamed: SW7.2 (3), SW8.2 (B)
unnamed: C6.1, SW7.3 (4)
unnamed: R8.2, RV23.1, U1.2 (-)
unnamed: RV22.2, U1.5 (+)
unnamed: R4.1, TP29.1 (1_1), U1.6 (-), U1.7
unnamed: C12.2, U2.2 (CAP+)
unnamed: C12.1, U2.4 (CAP-)
unnamed: R4.2, R5.1, U3.2 (-)
Rubber_soft_SouthA: D9.2 (A), Q2.2 (E), R3.1, R6.2, R25.1, SW6.3 (C), U3.6 (-)
Rubber_soft_SouthB: C7.1, D8.2 (A), Q1.2 (E), R3.2, R27.1, SW8.3 (C), TP27.1 (1_1), U3.7
V: D3.2 (A), J1.2
out: J5.4, R7.2

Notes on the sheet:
Output
input vol soft 100mV -> a few V
Soft Cliping
TN2106
-9V rail (from 9V)
Input Buffer
DC Power Input
Power LED
Output buffer -> line level
-9V rail
FootSwitch
Rubber Zener

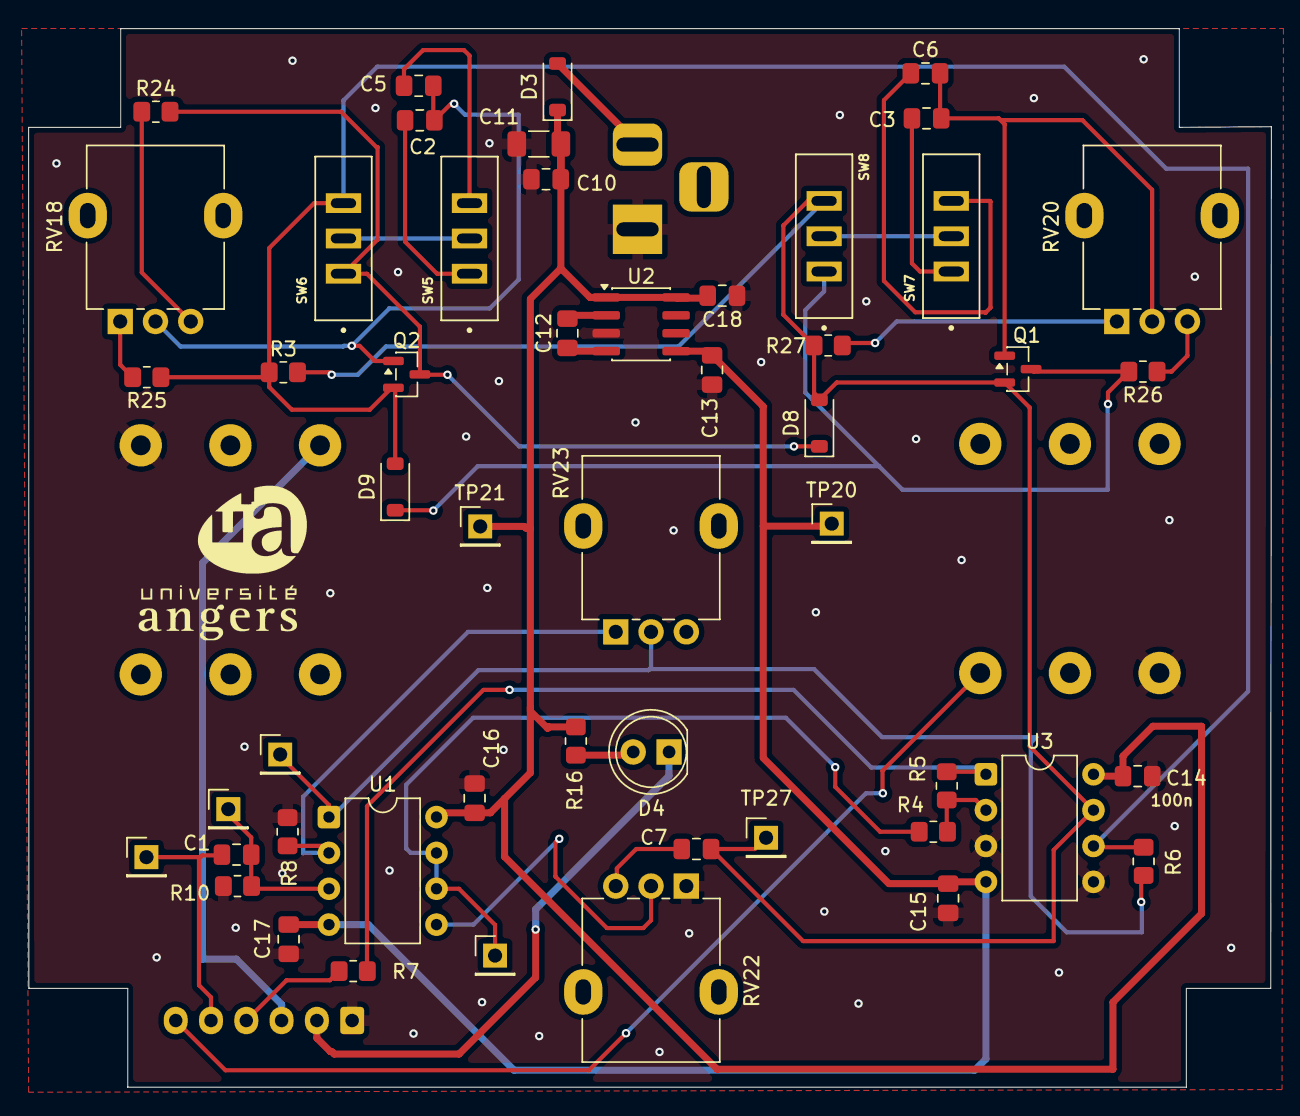
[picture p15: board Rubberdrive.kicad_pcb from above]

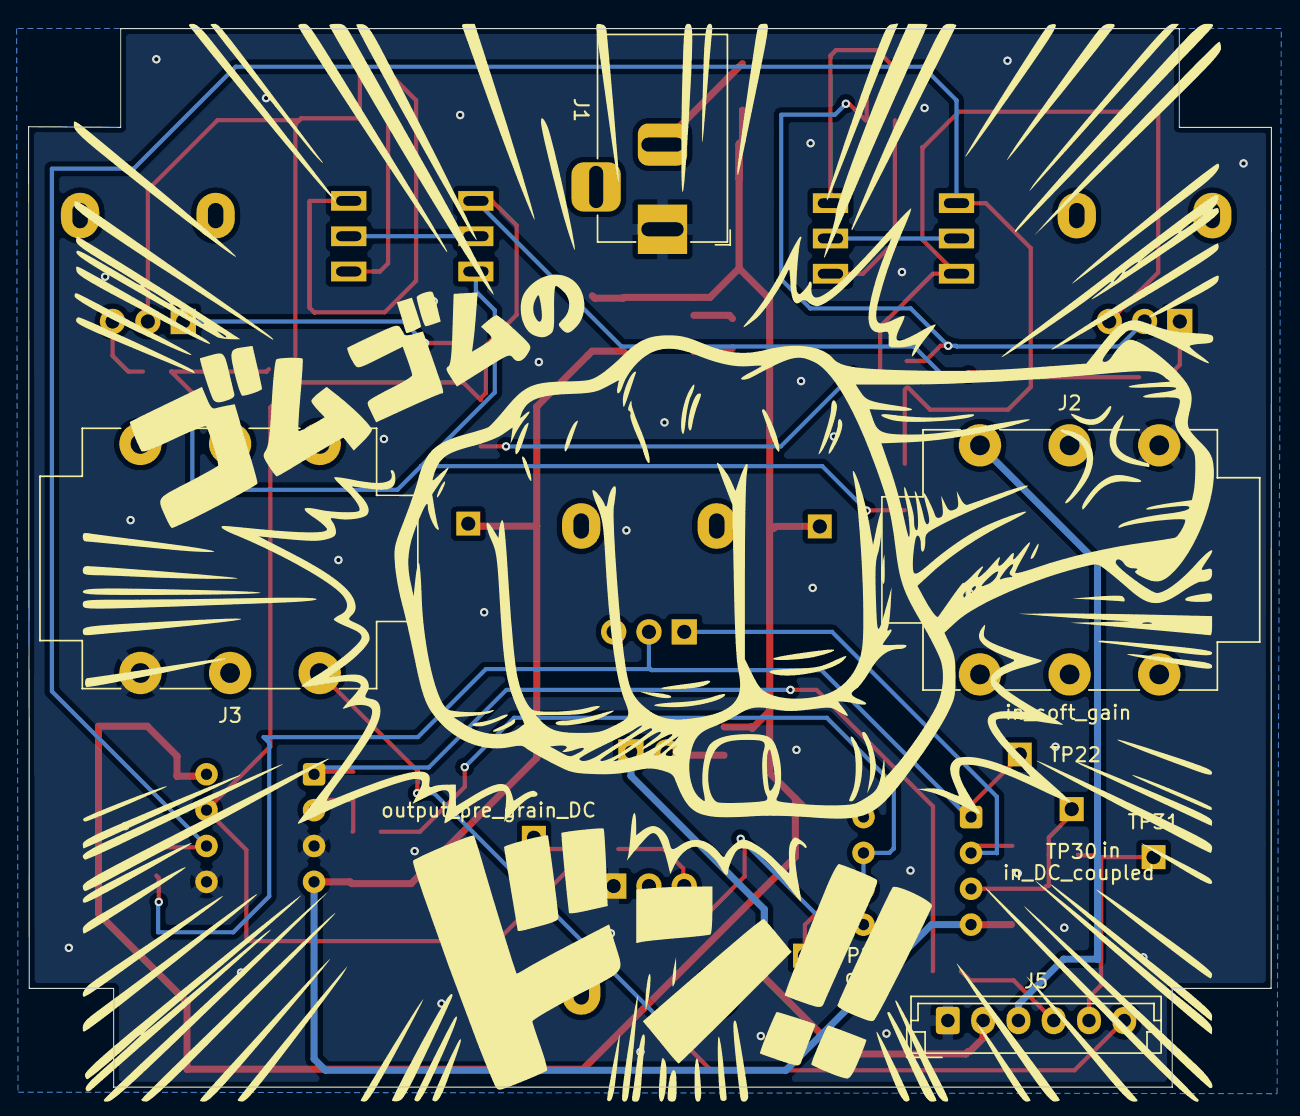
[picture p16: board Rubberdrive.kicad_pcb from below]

Board: 2 copper layers, 88.1 x 75.0 mm, 55 parts (4 on the bottom side), 36 nets.

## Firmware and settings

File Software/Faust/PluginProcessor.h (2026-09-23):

#pragma once

#include <juce_audio_processors/juce_audio_processors.h>
#include <juce_dsp/juce_dsp.h>
#include <array>
#include <atomic>
#include <cmath>
#include <algorithm>

// ==============================================================================
// OSCILLOSCOPE DATA STRUCTURE
// ==============================================================================
struct ScopeData {
    std::atomic<float> peakInPlus{0.0f};
    std::atomic<float> peakInMinus{0.0f};
    
    static constexpr int bufferSize = 512;
    std::array<float, bufferSize> bufferIn{};
    std::array<float, bufferSize> bufferOut{};
    std::atomic<int> writeIndex{0};
};

// ==============================================================================
// ADAA & MATH UTILITIES
// ==============================================================================
struct AdaaResult {
    double E;       // The anti-aliased exponential value
    double dE_dx;   // The exact derivative for the Jacobian matrix
};

// ==============================================================================
// CORE DSP CLASS: RubberZener (Dual Topology ODE Solver)
// ==============================================================================
class RubberZener {
public:
    RubberZener() = default;

    /**
     * @brief Resets the state-space memory of the ODE solver.
     * Call this when playback starts or is interrupted.
     */
    void reset() {
        for (int i = 0; i < 4; ++i) {
            X_up[i] = 0.0;
            X_dn[i] = 0.0;
        }
    }

    /**
     * @brief Processes a single audio sample through the dual-branch Rubber Zener ODE.
     * * @param vin      Input voltage sample
     * @param R_in     Global input series resistance (fixed to 10k)
     * @param dt       Time step (1.0 / SampleRate)
     * @param alpha_up Potentiometer position for the UP branch (0.0 to 1.0)
     * @param R_k_up   Series Knee resistor for UP branch
     * @param R_p_up   Pinch resistor for UP branch
     * @param C_up     Frequency-dependent capacitor for UP branch
     * @param pos_up   Capacitor position UP branch: 0 = Par. R_up, 1 = Par. R_low
     * @param alpha_dn Potentiometer position for the DOWN branch (0.0 to 1.0)
     * @param R_k_dn   Series Knee resistor for DOWN branch
     * @param R_p_dn   Pinch resistor for DOWN branch
     * @param C_dn     Frequency-dependent capacitor for DOWN branch
     * @param pos_dn   Capacitor position DOWN branch: 0 = Par. R_up, 1 = Par. R_low
     * @return double  The processed output voltage sample
     */
    double processSample(double vin, double R_in, double dt, 
                         double alpha_up, double R_k_up, double R_p_up, double C_up, int pos_up,
                         double alpha_dn, double R_k_dn, double R_p_dn, double C_dn, int pos_dn);

private:
    // --- STATE SPACE VECTORS ---
    // X[0] = V_up (Voltage across R_up)
    // X[1] = V_be (Voltage Base-Emitter)
    // X[2] = V_bc (Voltage Base-Collector)
    // X[3] = V_d  (Voltage across the Schottky Diode)
    double X_up[4] = {0.0, 0.0, 0.0, 0.0};
    double X_dn[4] = {0.0, 0.0, 0.0, 0.0};
    
    // --- PHYSICAL CONSTANTS (Ebers-Moll & Shockley) ---
    static constexpr double V_T  = 0.026;       // Thermal voltage at 25C
    static constexpr double I_S  = 7.049e-15;   // BJT Saturation current (BC550)
    static constexpr double B_F  = 493.2;       // Forward Beta
    static constexpr double B_R  = 2.886;       // Reverse Beta (critical for hard clipping)
    static constexpr double I_SD = 21e-9;       // Schottky Diode Saturation current (BAT54)
    static constexpr double R_D  = 1.0;         // Schottky intrinsic series resistance

    // --- INTERNAL METHODS ---
    AdaaResult adaa_exp(double v, double vp, double Vt);
    bool solveLinearSystem4x4(const double J[4][4], const double F[4], double dX[4]);
    void solve_ebers_moll_step(double X[4], double vin, double dt, double C, 
                               double R_up, double R_low, double R_p, double R_s, int cap_pos);
};

// ==============================================================================
// JUCE AUDIO PROCESSOR
// ==============================================================================
class GomuGomuNoDrive final : public juce::AudioProcessor
{
public:
    GomuGomuNoDrive();
    ~GomuGomuNoDrive() override;

    void prepareToPlay (double sampleRate, int samplesPerBlock) override;
    void releaseResources() override;
    bool isBusesLayoutSupported (const BusesLayout& layouts) const override;
    void processBlock (juce::AudioBuffer<float>&, juce::MidiBuffer&) override;
    using AudioProcessor::processBlock;

    juce::AudioProcessorEditor* createEditor() override;
    bool hasEditor() const override;

    const juce::String getName() const override;
    bool acceptsMidi() const override;
    bool producesMidi() const override;
    bool isMidiEffect() const override;
    double getTailLengthSeconds() const override;

    int getNumPrograms() override;
    int getCurrentProgram() override;
    void setCurrentProgram (int index) override;
    const juce::String getProgramName (int index) override;
    void changeProgramName (int index, const juce::String& newName) override;

    void getStateInformation (juce::MemoryBlock& destData) override;
    void setStateInformation (const void* data, int sizeInBytes) override;

    juce::AudioProcessorValueTreeState apvts;
    ScopeData scopeData; 

private:
    juce::AudioProcessorValueTreeState::ParameterLayout createParameters();

    std::unique_ptr<juce::dsp::Oversampling<float>> oversampler;
    RubberZener clippers[2];

    // Global Input
    std::atomic<float>* inGainParam = nullptr;

    // Positive Branch (UP) Parameters
    std::atomic<float>* threshPlusParam = nullptr;  // Maps to Alpha UP
    std::atomic<float>* capPlusParam = nullptr;
    std::atomic<float>* pinchPlusParam = nullptr;
    std::atomic<float>* kneePlusParam = nullptr;    // Maps to R_k UP
    std::atomic<float>* transPlusParam = nullptr;   // Unused for now (forced BJT)
    std::atomic<float>* capPosPlusParam = nullptr;

    // Negative Branch (DOWN) Parameters
    std::atomic<float>* threshMinusParam = nullptr; // Maps to Alpha DN
    std::atomic<float>* capMinusParam = nullptr;
    std::atomic<float>* pinchMinusParam = nullptr;
    std::atomic<float>* kneeMinusParam = nullptr;   // Maps to R_k DN
    std::atomic<float>* transMinusParam = nullptr;  // Unused for now
    std::atomic<float>* capPosMinusParam = nullptr;

    JUCE_DECLARE_NON_COPYABLE_WITH_LEAK_DETECTOR (GomuGomuNoDrive)
};
